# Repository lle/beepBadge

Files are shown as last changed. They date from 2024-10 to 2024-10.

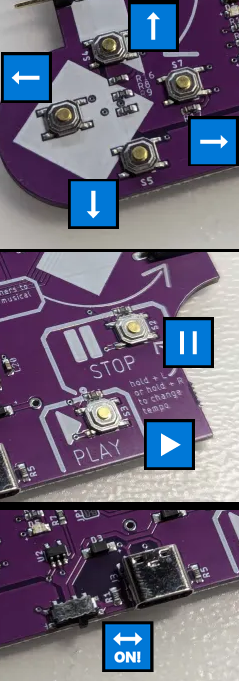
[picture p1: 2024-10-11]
img/nav.png

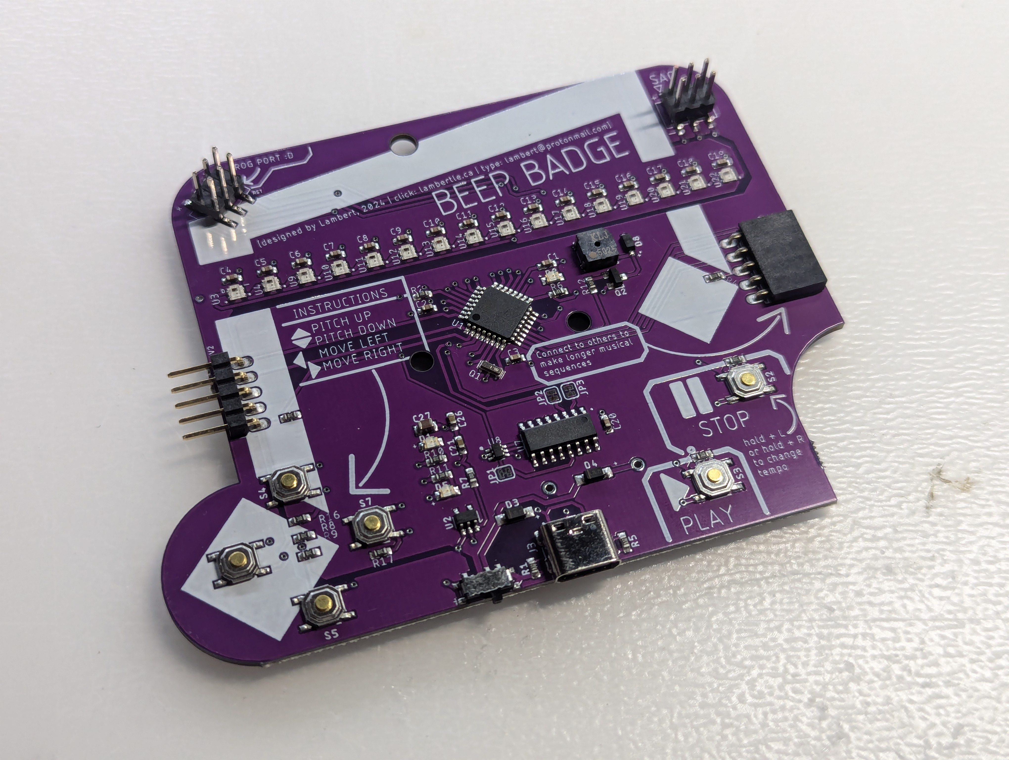
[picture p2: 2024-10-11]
img/ads.jpg

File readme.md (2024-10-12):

# BEEP BADGE
This project is inspired from a mix of concepts between an old product I was working on at my ex-job, a badge I wanted to make for a rave, the animal crossing tune creator. 
Result: a weird beeper badge XD

## Instruction
Go meet people at the con. Plug your badges together. The first person on the left presses "PLAY". The badge will start playing their 
tunes from left to right. Go make the coolest musical sequence!

## How to Program
Use an Atmel USB-ISP (USBASP) to flash the firmware. There is a programming connector at the top left of the badge labeled "Prog Port". Note the positive (+), negative (-) and reset (rst) label around the connector. Use it to match with the pinout of the USB-ISP. 
I used VScode+platformio to program and compile the firmware

## Acknowledgment
I would like to thank Angel for their help in beta-testing the badge as they are much 
more musically inclined than 
I will ever be ^.^

Parts of the design from the Northsec Pegasis badge and the "Hello my name is" badge was used to rush the design of this badge.

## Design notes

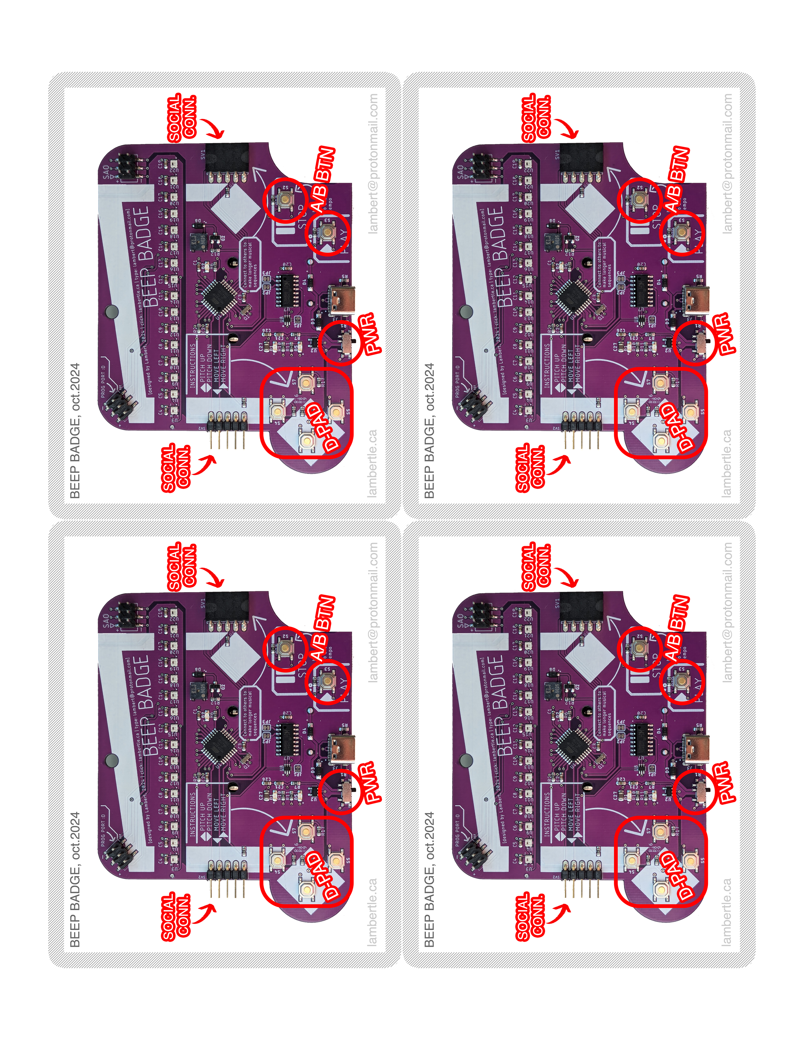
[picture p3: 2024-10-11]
img/frontpage.png

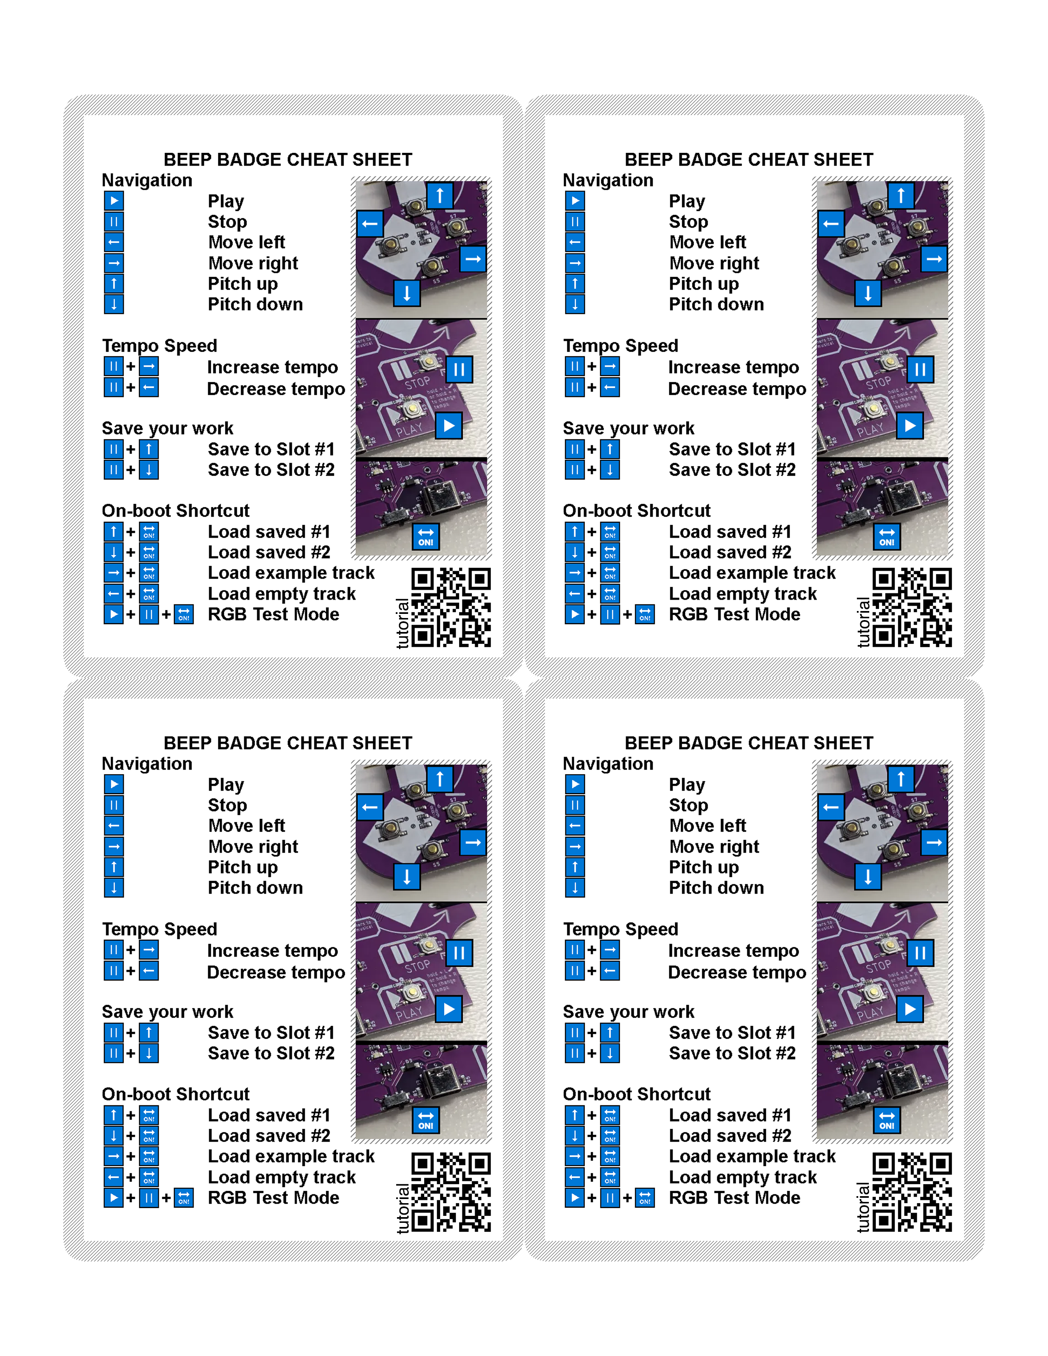
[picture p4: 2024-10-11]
img/cheatSheet.png

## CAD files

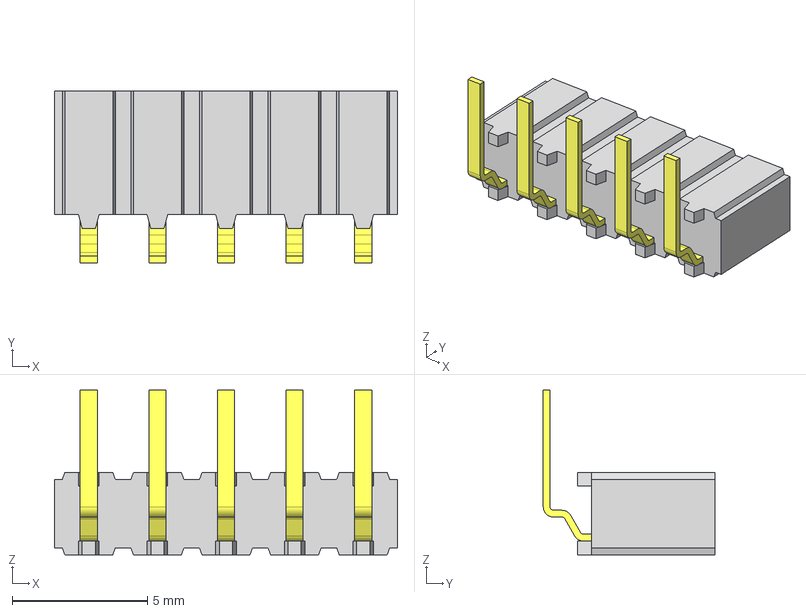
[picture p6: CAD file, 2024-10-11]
hw/cad/5pinFemale_CES-105-02-T-S-RA.stp
12.7 x 6.35 x 6.10 mm
010502SRA
CES-105-01-S_socket

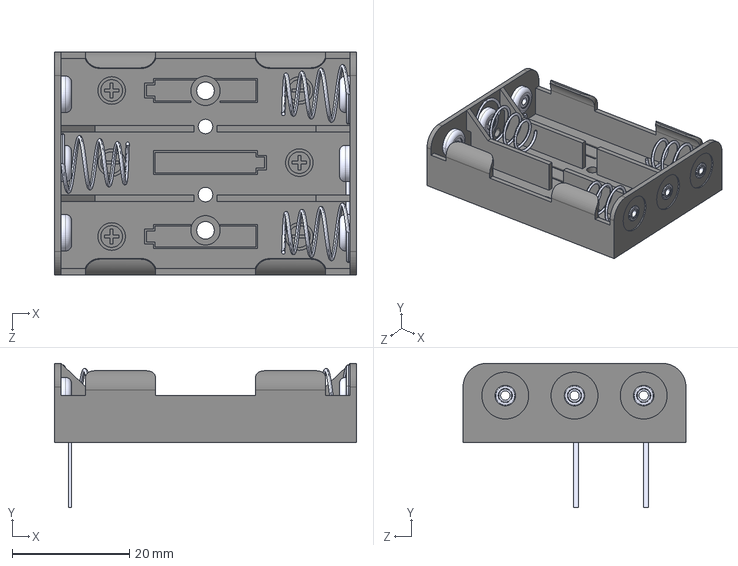
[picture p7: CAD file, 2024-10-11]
hw/cad/BC3AAAPC-battery3x-STEP-56544.STEP
51.5 x 24.6 x 38.0 mm

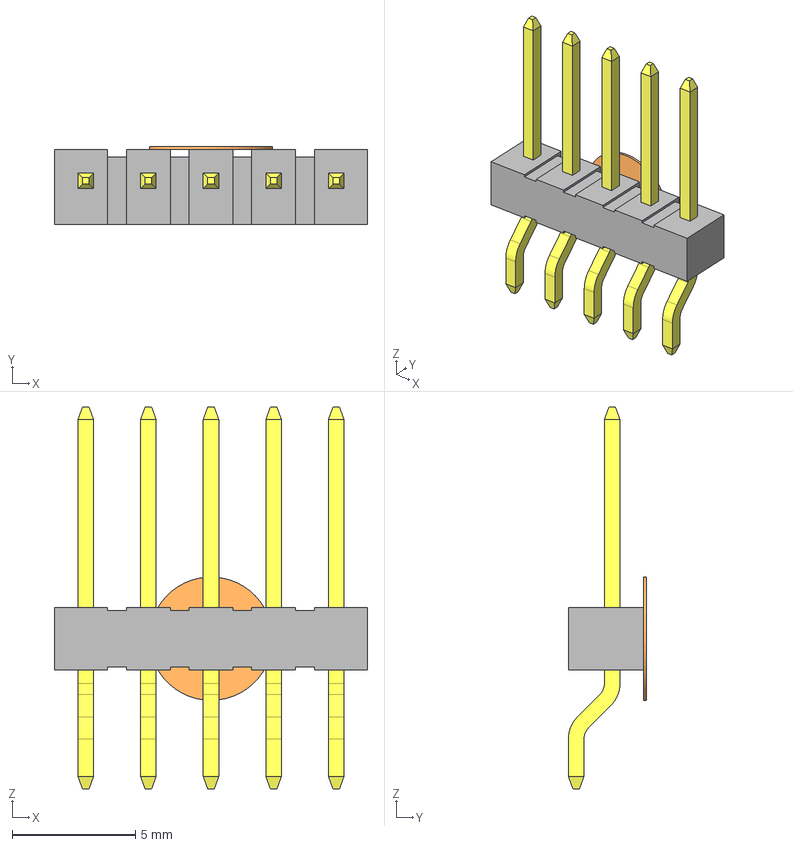
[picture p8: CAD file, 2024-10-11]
hw/cad/5pinMale_TSM-105-02-S-SH-K.stp
12.7 x 3.18 x 15.5 mm
T-1S6-15(-02-5-SH)
TSM_polyimide_film
TSM-105-02-SH_body

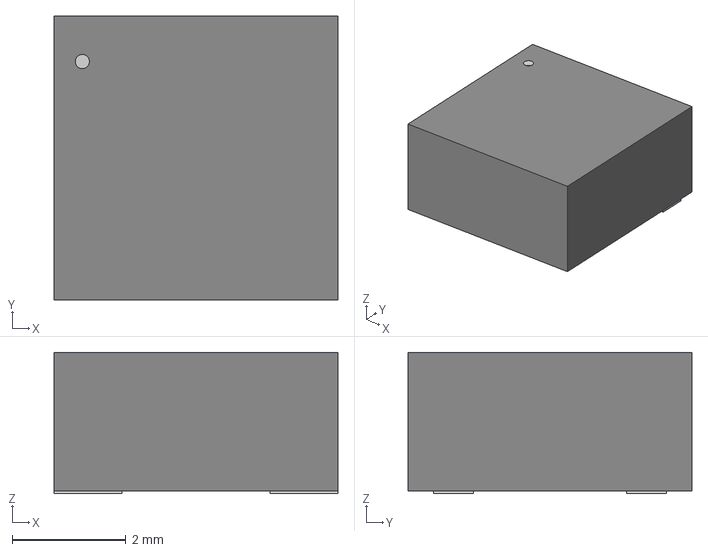
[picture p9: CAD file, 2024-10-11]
hw/cad/KLJ-5025_KKG.step
5.00 x 5.00 x 2.49 mm

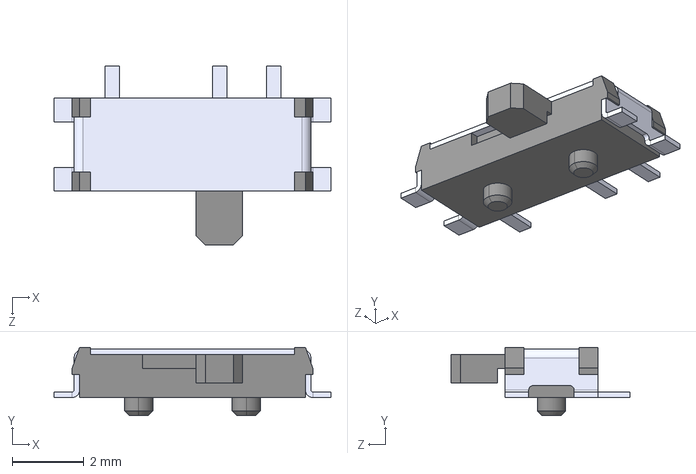
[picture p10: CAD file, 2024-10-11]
hw/cad/PCM12SMTR-powerSw-STEP-56544.STEP
7.72 x 1.91 x 4.98 mm

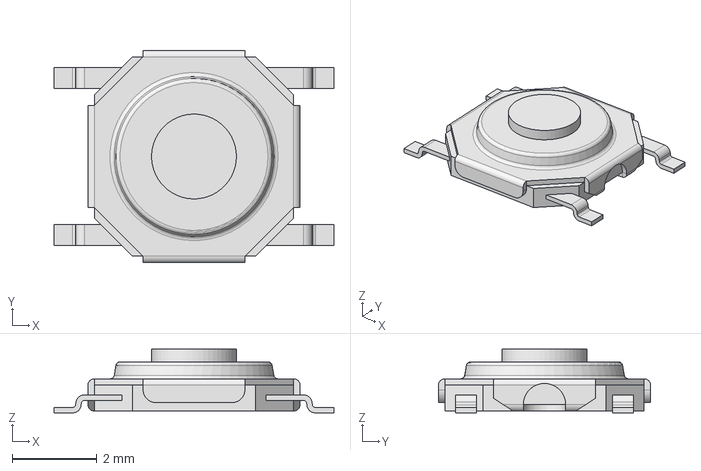
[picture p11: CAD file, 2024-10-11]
hw/cad/TL3342F160QG-tactileSw-STEP-520916.STEP
6.60 x 5.00 x 1.50 mm

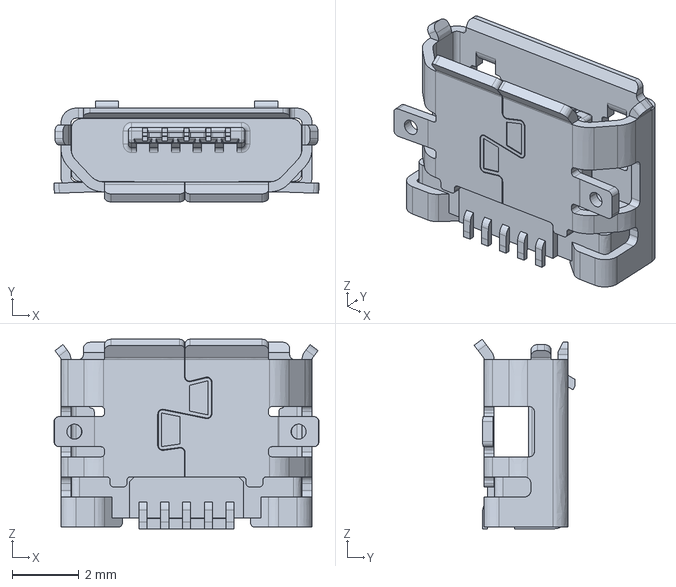
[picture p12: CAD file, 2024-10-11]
hw/cad/10118192-0001LF-microUSB-STEP-533217.STEP
7.91 x 3.01 x 5.66 mm

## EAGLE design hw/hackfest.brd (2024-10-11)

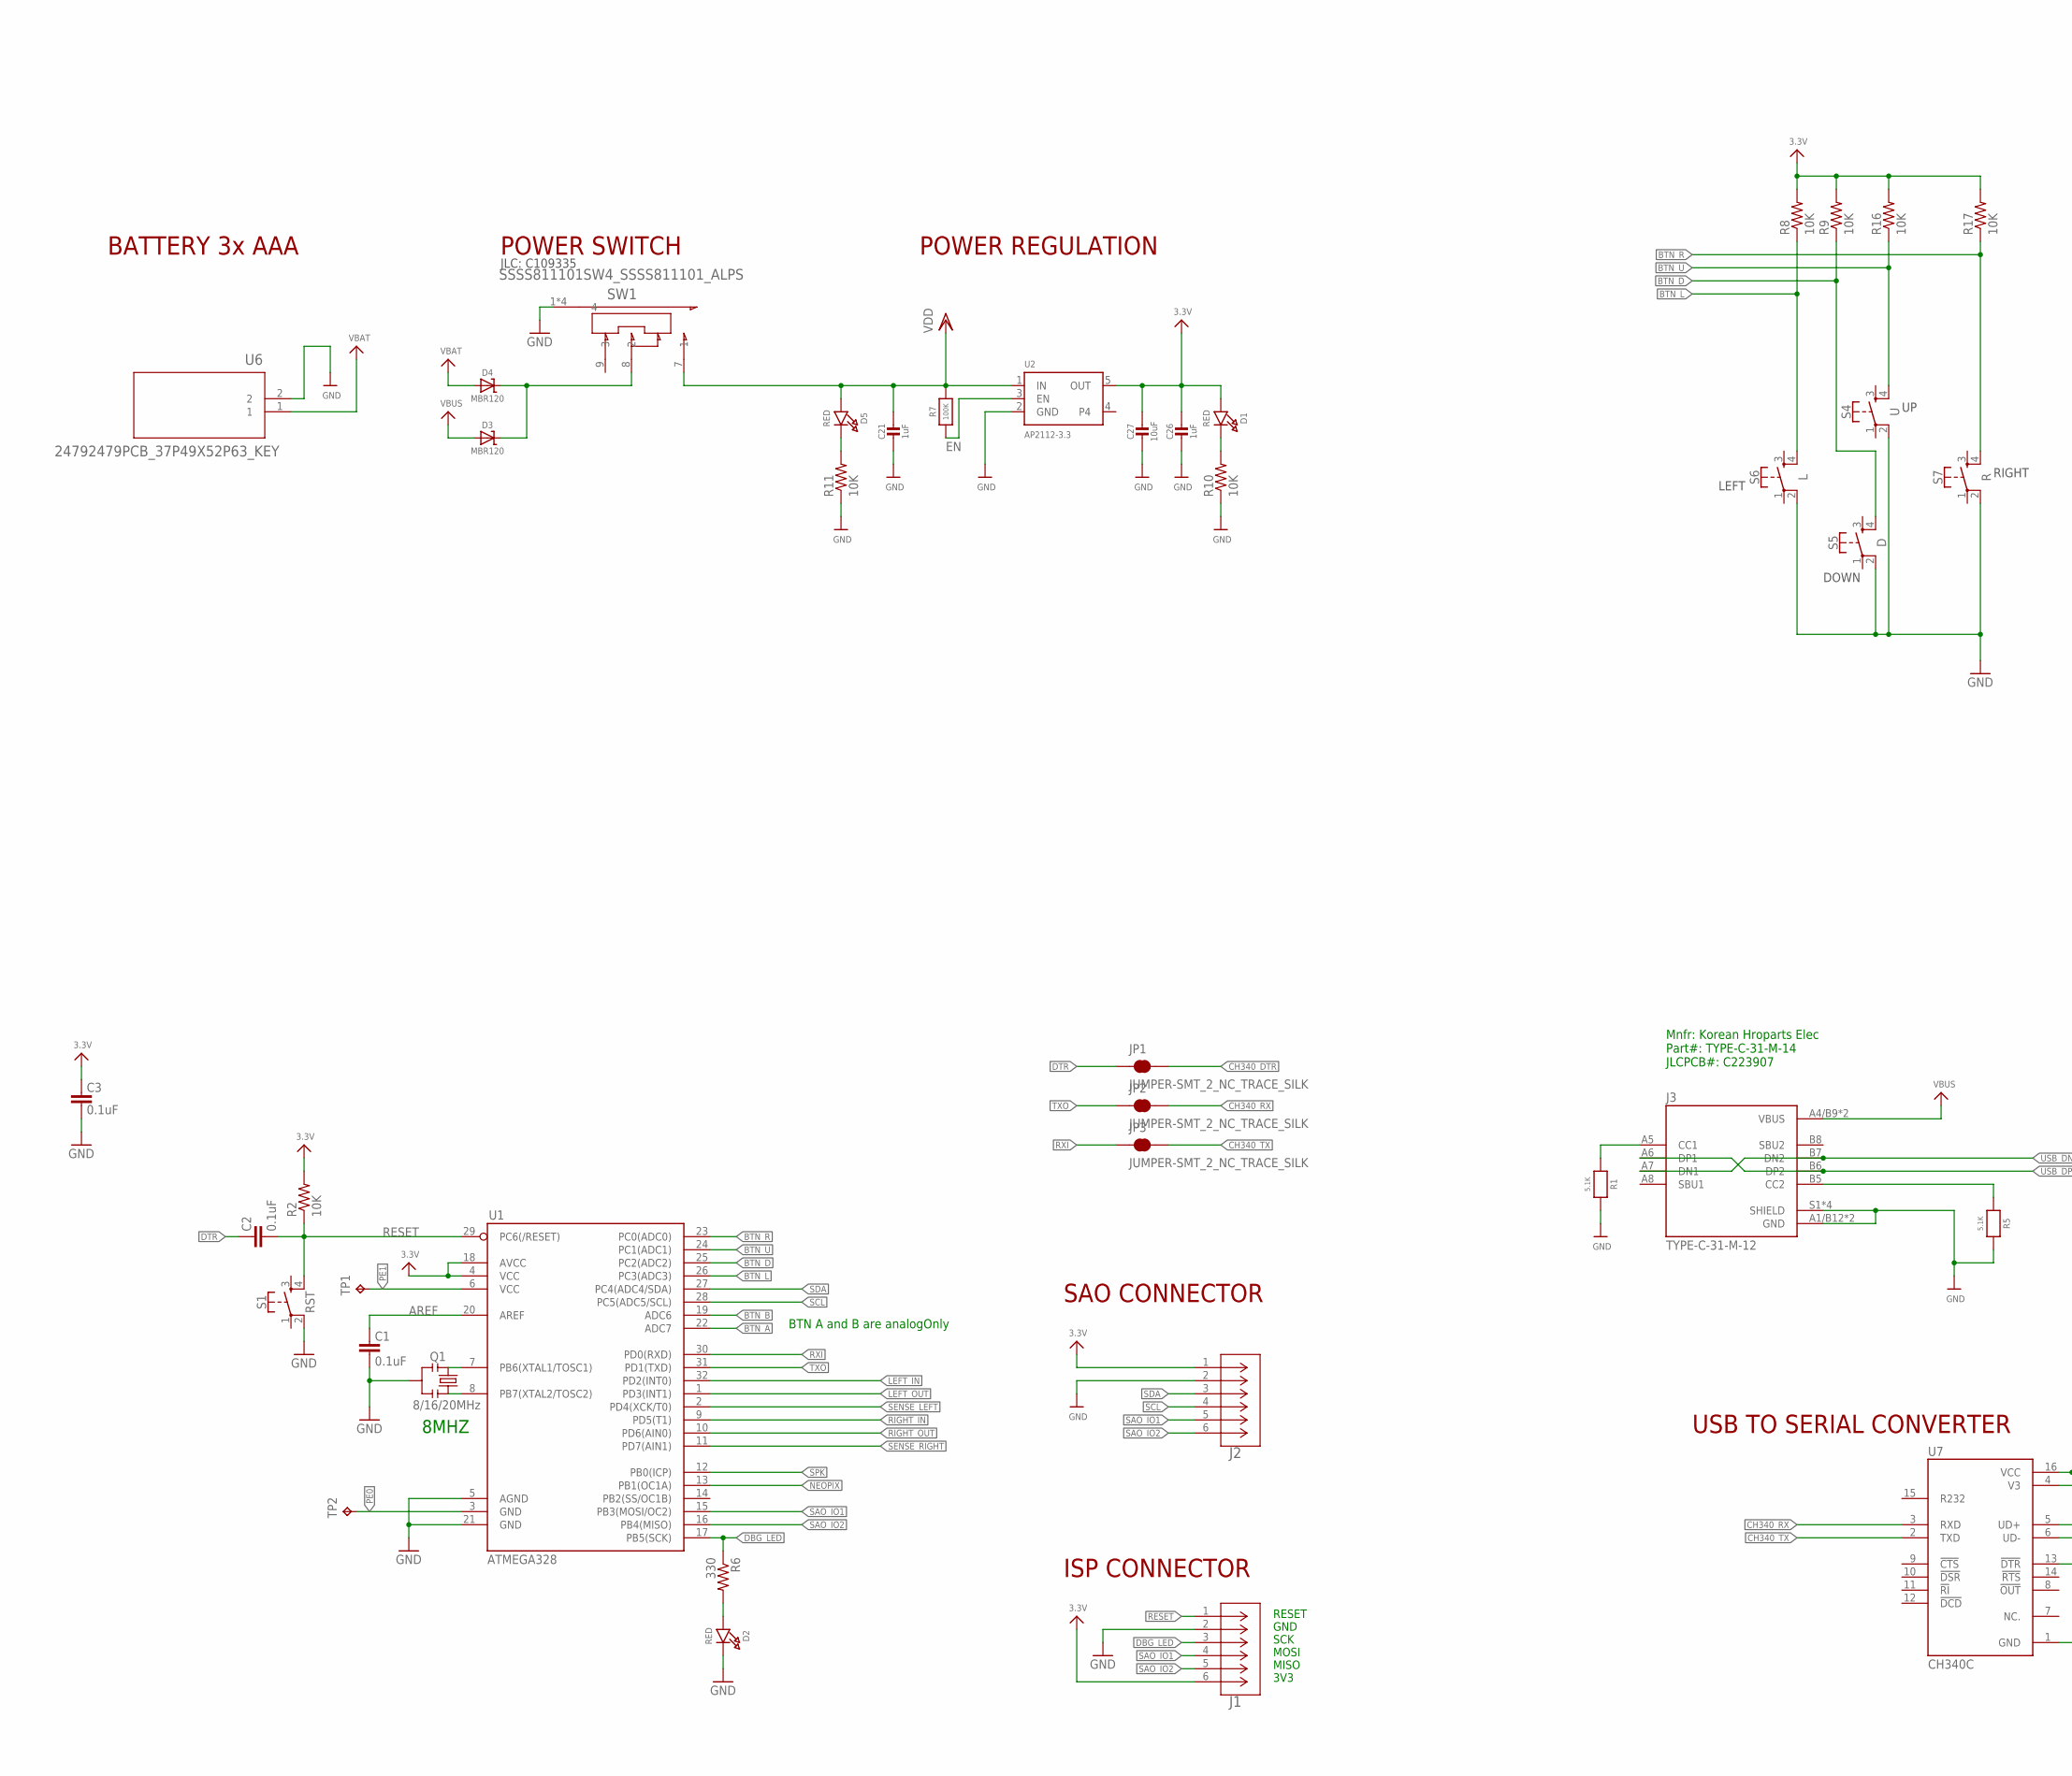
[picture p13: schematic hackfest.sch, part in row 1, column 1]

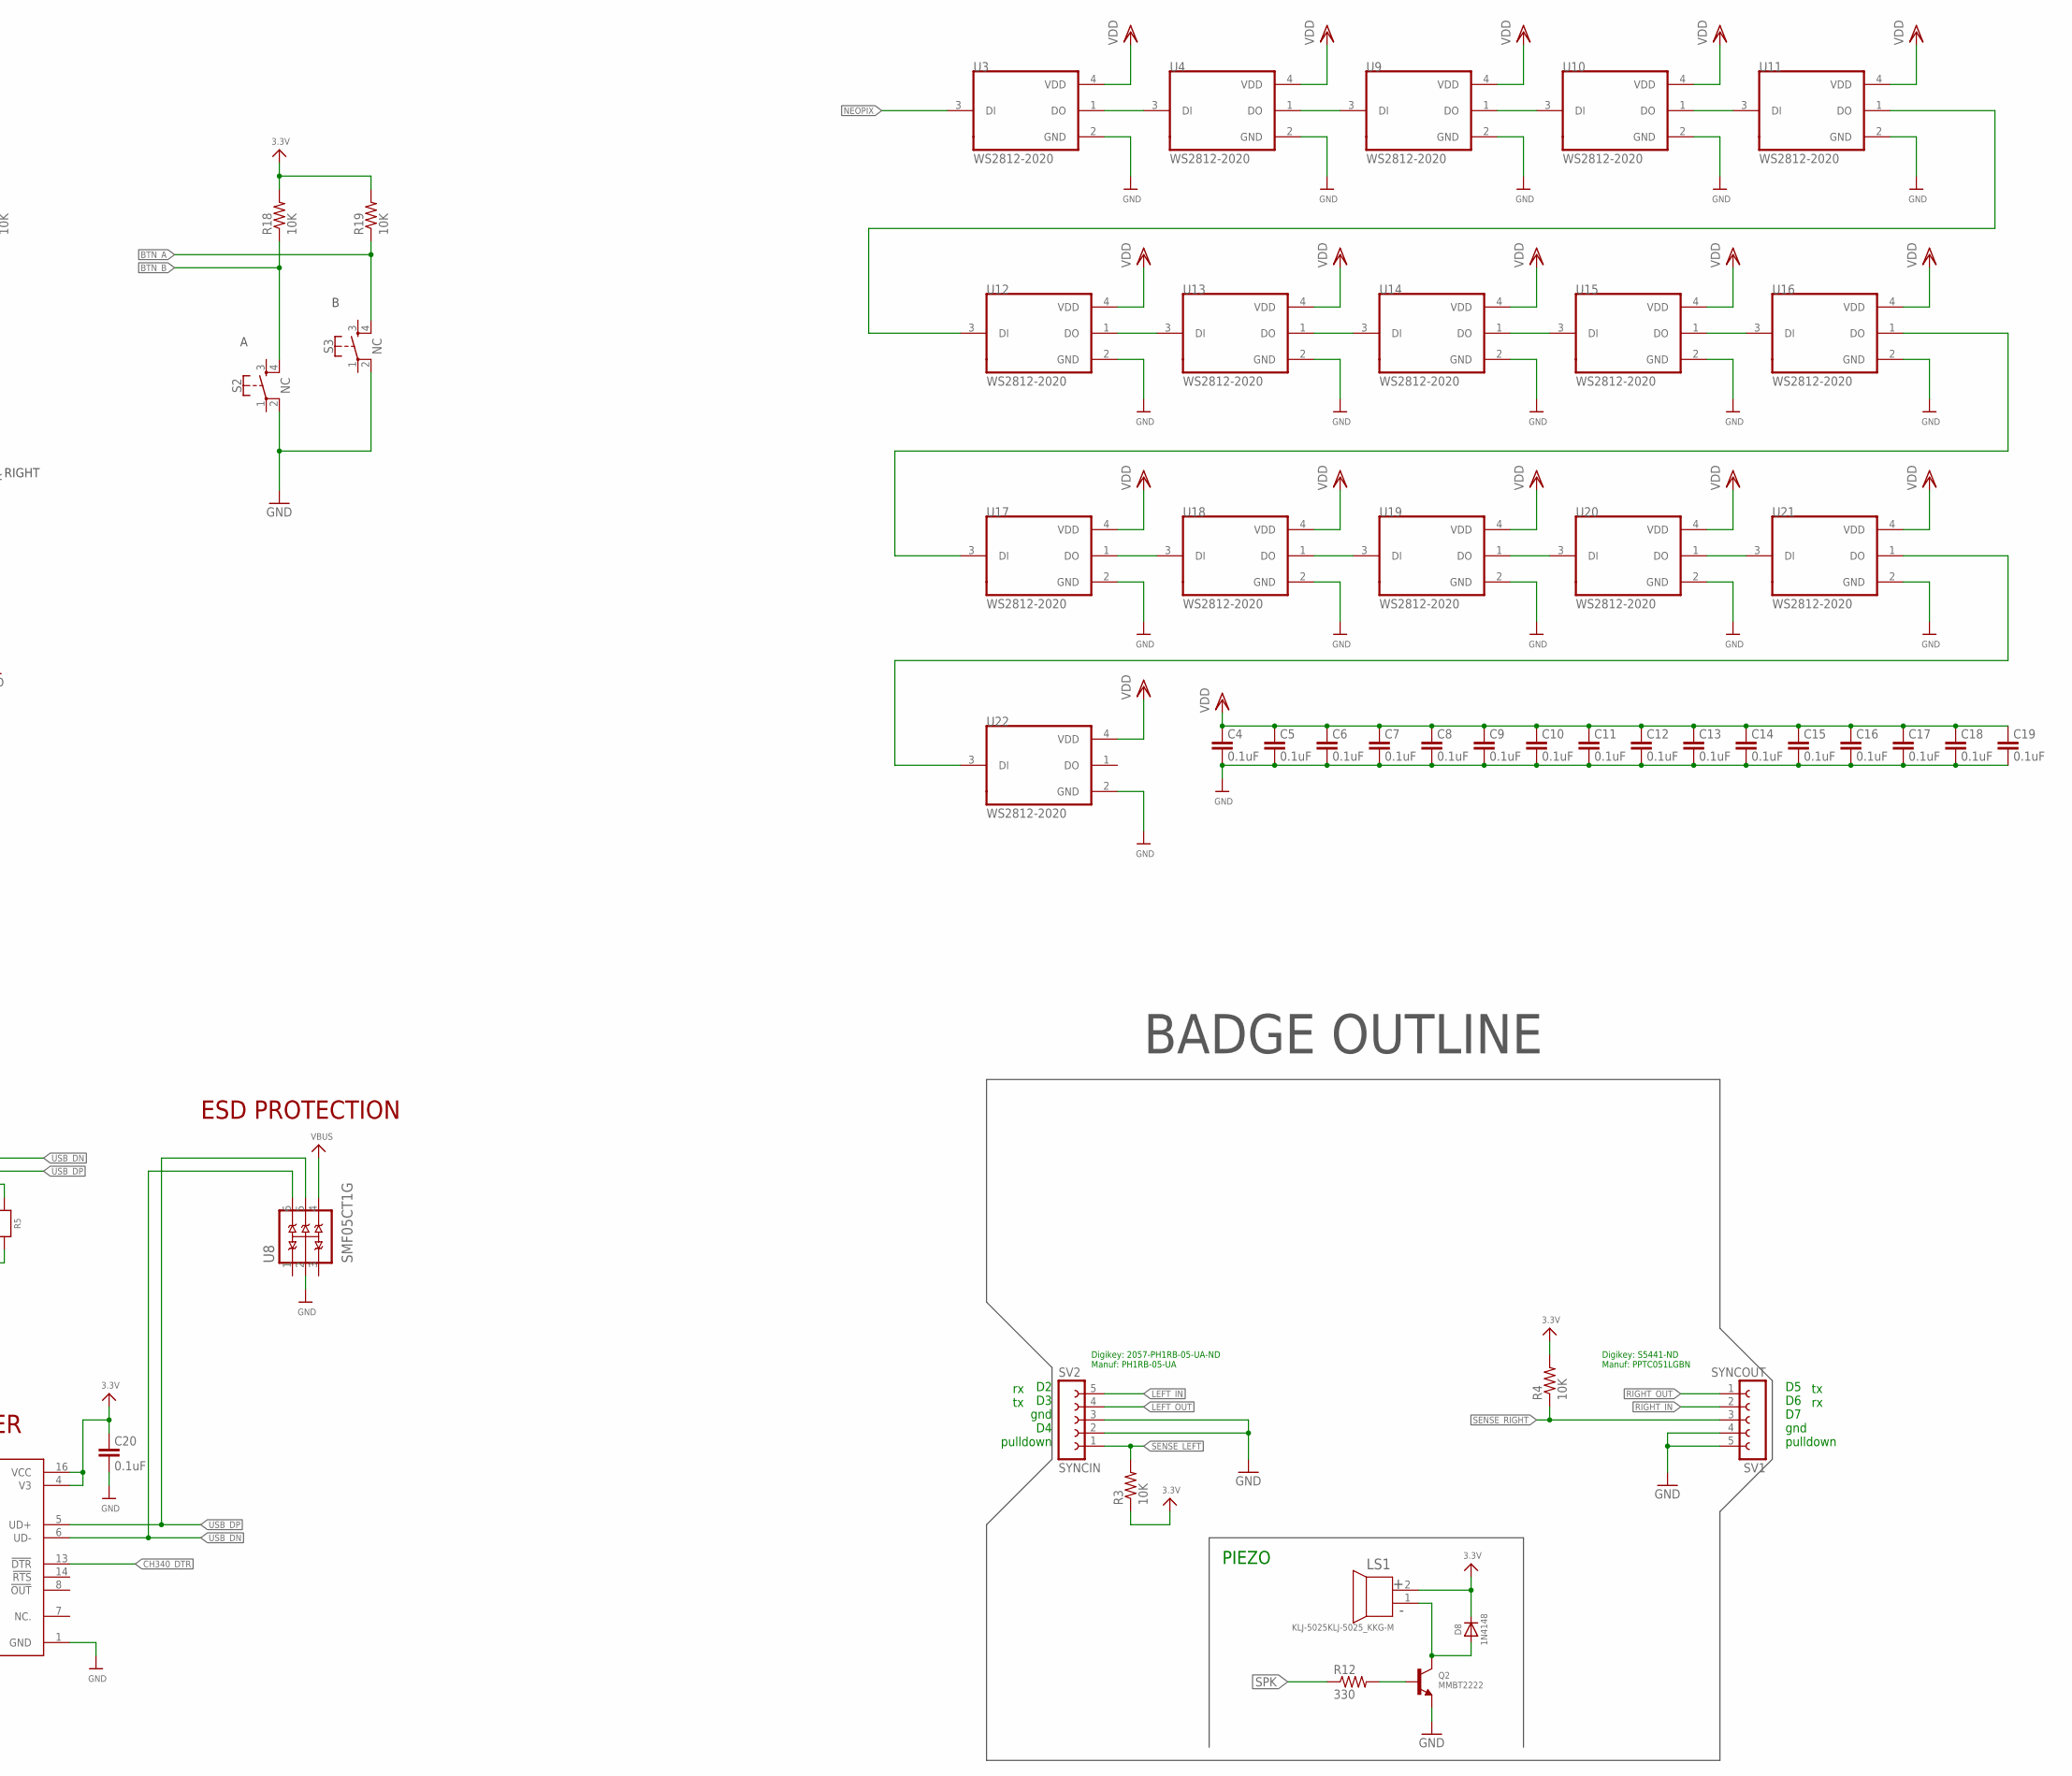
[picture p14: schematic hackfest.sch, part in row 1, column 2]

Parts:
C1, C2, C3, C4, C5, C6, C7, C8, C9, C10, C11, C12, C13, C14, C15, C16, C17, C18, C19, C20: 0.1uF; 0603-CAP
C21, C26: 1uF; 0603-NO@1
C27: 10uF; 0805-NO
D1, D2, D5: RED; CHIPLED_0805_NOOUTLINE
D3, D4: MBR120; SOD-123
D8: 1N4148; SOD-323
J1, J2: SSW-103-22-F-D-VS-K-TRCON3_SSW-D-DUMZ_HDR_SAI; CON3_SSW-D-DUMZ_HDR_SAI
J3: TYPE-C-31-M-12; HRO_TYPE-C-31-M-12
JP1, JP2, JP3: JUMPER-SMT_2_NC_TRACE_SILK; SMT-JUMPER_2_NC_TRACE_SILK
LS1: KLJ-5025KLJ-5025_KKG-M; KLJ-5025_KKG-M
Q1: 8/16/20MHz; RESONATOR-SMD-1:1
Q2: MMBT2222; SOT23-WIDE
R1, R5: 5.1K; 0603-NO
R2, R3, R4, R8, R9, R10, R11, R16, R17, R18, R19: 10K; 0603-RES
R6, R12: 330; 0603-RES
R7: 100K; 0603-NO
S1: RST; TACTILE_SWITCH_SMD_5.2MM
S2, S3: NC; TACTILE_SWITCH_SMD_5.2MM
S4: U; TACTILE_SWITCH_SMD_5.2MM
S5: D; TACTILE_SWITCH_SMD_5.2MM
S6: L; TACTILE_SWITCH_SMD_5.2MM
S7: R; TACTILE_SWITCH_SMD_5.2MM
SV1: SYNCOUT; FE05W
SV2: SYNCIN; FE05W
SW1: SSSS811101SW4_SSSS811101_ALPS; SW4_SSSS811101_ALPS
TP1, TP2: TPB1,27; B1,27
U1: ATMEGA328; TQFP32-08
U2: AP2112-3.3; SOT23-5
U3, U4, U9, U10, U11, U12, U13, U14, U15, U16, U17, U18, U19, U20, U21, U22: WS2812-2020; LED_WS2812-2020
U6: 24792479PCB_37P49X52P63_KEY; 2479PCB_37P49X52P63_KEY
U7: CH340C; SOIC127P600X180-16N
U8: SMF05CT1G; SOT65P210X110-6N

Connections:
3.3V: C3.2, C20.2, C26.1, C27.1, D1.A, D8.C, J1.6, J2.1, LS1.2, R2.2, R3.1, R4.2, R8.2, R9.2, R16.2, R17.2, R18.2, R19.2, U1.4 (VCC), U1.18 (AVCC), U2.5 (OUT), U7.4 (V3), U7.16 (VCC)
AREF: C1.2, U1.20 (AREF)
BTN_A: R19.1, S3.4, U1.22 (ADC7)
BTN_B: R18.1, S2.4, U1.19 (ADC6)
BTN_D: R9.1, S5.4, U1.25 (PC2(ADC2))
BTN_L: R8.1, S6.4, U1.26 (PC3(ADC3))
BTN_R: R17.1, S7.4, U1.23 (PC0(ADC0))
BTN_U: R16.1, S4.4, U1.24 (PC1(ADC1))
CH340_DTR: JP1.2, U7.13 (!DTR)
CH340_RX: JP2.2, U7.3 (RXD)
CH340_TX: JP3.2, U7.2 (TXD)
DBG_LED: J1.3, R6.1, U1.17 (PB5(SCK))
DTR: C2.2, JP1.1
EN: R7.1, U2.3 (EN)
GND: C1.1, C3.1, C4.1, C5.1, C6.1, C7.1, C8.1, C9.1, C10.1, C11.1, C12.1, C13.1, C14.1, C15.1, C16.1, C17.1, C18.1, C19.1, C20.1, C21.2, C26.2, C27.2, D2.C, J1.2, J2.2, J3.A1/B12 (GND), J3.B1/A12 (GND), J3.S1 (SHIELD), J3.S2 (SHIELD), J3.S3 (SHIELD), J3.S4 (SHIELD), Q1.2, Q2.2 (E), R1.2, R5.2, R10.1, R11.1, S1.2, S2.2, S3.2, S4.2, S5.2, S6.2, S7.2, SV1.4, SV1.5, SV2.2, SV2.3, SW1.1 (4), SW1.2 (4), SW1.3 (4), SW1.4, U1.5 (AGND), U1.21 (GND), U2.2 (GND), U3.2 (GND), U4.2 (GND), U6.2, U7.1 (GND), U8.2 (A), U9.2 (GND), U10.2 (GND), U11.2 (GND), U12.2 (GND), U13.2 (GND), U14.2 (GND), U15.2 (GND), U16.2 (GND), U17.2 (GND), U18.2 (GND), U19.2 (GND), U20.2 (GND), U21.2 (GND), U22.2 (GND)
LEFT_IN: SV2.5, U1.32 (PD2(INT0))
LEFT_OUT: SV2.4, U1.1 (PD3(INT1))
unnamed: Q1.3, U1.8 (PB7(XTAL2/TOSC2))
unnamed: Q1.1, U1.7 (PB6(XTAL1/TOSC1))
unnamed: U4.1 (DO), U9.3 (DI)
unnamed: U9.1 (DO), U10.3 (DI)
unnamed: U3.1 (DO), U4.3 (DI)
unnamed: U10.1 (DO), U11.3 (DI)
unnamed: D2.A, R6.2
unnamed: U11.1 (DO), U12.3 (DI)
unnamed: U12.1 (DO), U13.3 (DI)
unnamed: U13.1 (DO), U14.3 (DI)
unnamed: U14.1 (DO), U15.3 (DI)
unnamed: U15.1 (DO), U16.3 (DI)
unnamed: U16.1 (DO), U17.3 (DI)
unnamed: U17.1 (DO), U18.3 (DI)
unnamed: U18.1 (DO), U19.3 (DI)
unnamed: U19.1 (DO), U20.3 (DI)
unnamed: U20.1 (DO), U21.3 (DI)
unnamed: U21.1 (DO), U22.3 (DI)
unnamed: D8.A, LS1.1, Q2.3 (C)
unnamed: Q2.1 (B), R12.2
unnamed: J3.B5 (CC2), R5.1
unnamed: J3.A5 (CC1), R1.1
unnamed: D3.C, D4.C, SW1.8 (2)
unnamed: D5.C, R11.2
unnamed: D1.C, R10.2
NEOPIX: U1.13 (PB1(OC1A)), U3.3 (DI)
PE0: TP2.TP, U1.3 (GND)
PE1: TP1.TP, U1.6 (VCC)
RESET: C2.1, J1.1, R2.1, S1.4, U1.29 (PC6(/RESET))
RIGHT_IN: SV1.2, U1.9 (PD5(T1))
RIGHT_OUT: SV1.1, U1.10 (PD6(AIN0))
RXI: JP3.1, U1.30 (PD0(RXD))
SAO_IO1: J1.4, J2.5, U1.15 (PB3(MOSI/OC2))
SAO_IO2: J1.5, J2.6, U1.16 (PB4(MISO))
SCL: J2.4, U1.28 (PC5(ADC5/SCL))
SDA: J2.3, U1.27 (PC4(ADC4/SDA))
SENSE_LEFT: R3.2, SV2.1, U1.2 (PD4(XCK/T0))
SENSE_RIGHT: R4.1, SV1.3, U1.11 (PD7(AIN1))
SPK: R12.1, U1.12 (PB0(ICP))
TXO: JP2.1, U1.31 (PD1(TXD))
USB_DN: J3.A7 (DN1), J3.B7 (DN2), U7.6 (UD-), U8.6 (C5)
USB_DP: J3.A6 (DP1), J3.B6 (DP2), U7.5 (UD+), U8.5 (C4)
VBAT: D4.A, U6.1
VBUS: D3.A, J3.A4/B9 (VBUS), J3.B4/A9 (VBUS), U8.4 (C3)
VDD: C4.2, C5.2, C6.2, C7.2, C8.2, C9.2, C10.2, C11.2, C12.2, C13.2, C14.2, C15.2, C16.2, C17.2, C18.2, C19.2, C21.1, D5.A, R7.2, SW1.7 (1), U2.1 (IN), U3.4 (VDD), U4.4 (VDD), U9.4 (VDD), U10.4 (VDD), U11.4 (VDD), U12.4 (VDD), U13.4 (VDD), U14.4 (VDD), U15.4 (VDD), U16.4 (VDD), U17.4 (VDD), U18.4 (VDD), U19.4 (VDD), U20.4 (VDD), U21.4 (VDD), U22.4 (VDD)

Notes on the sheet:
POWER REGULATION
BATTERY 3x AAA
DOWN
LEFT
RIGHT
USB TO SERIAL CONVERTER
ESD PROTECTION
BADGE OUTLINE
Mnfr: Korean Hroparts Elec Part#: TYPE-C-31-M-14 JLCPCB#: C223907
SAO CONNECTOR
RESET GND SCK MOSI MISO 3V3
ISP CONNECTOR
Digikey: S5441-ND Manuf: PPTC051LGBN
Digikey: 2057-PH1RB-05-UA-ND Manuf: PH1RB-05-UA
8MHZ
D2 D3 gnd D4 pulldown
D5 D6 D7 gnd pulldown
rx tx
tx rx
BTN A and B are analogOnly
PIEZO
JLC: C109335
POWER SWITCH

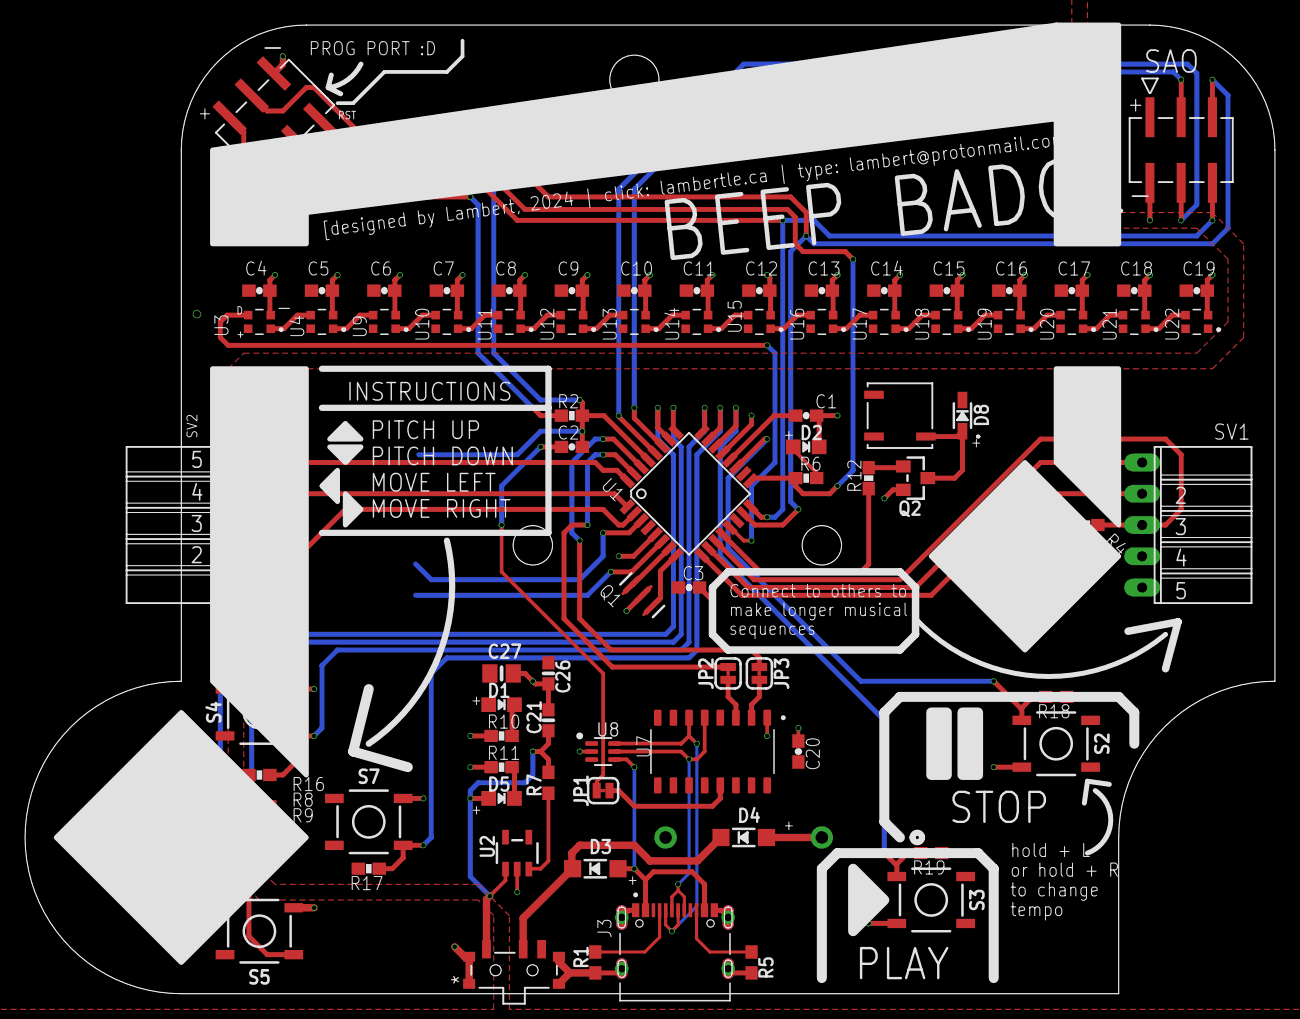
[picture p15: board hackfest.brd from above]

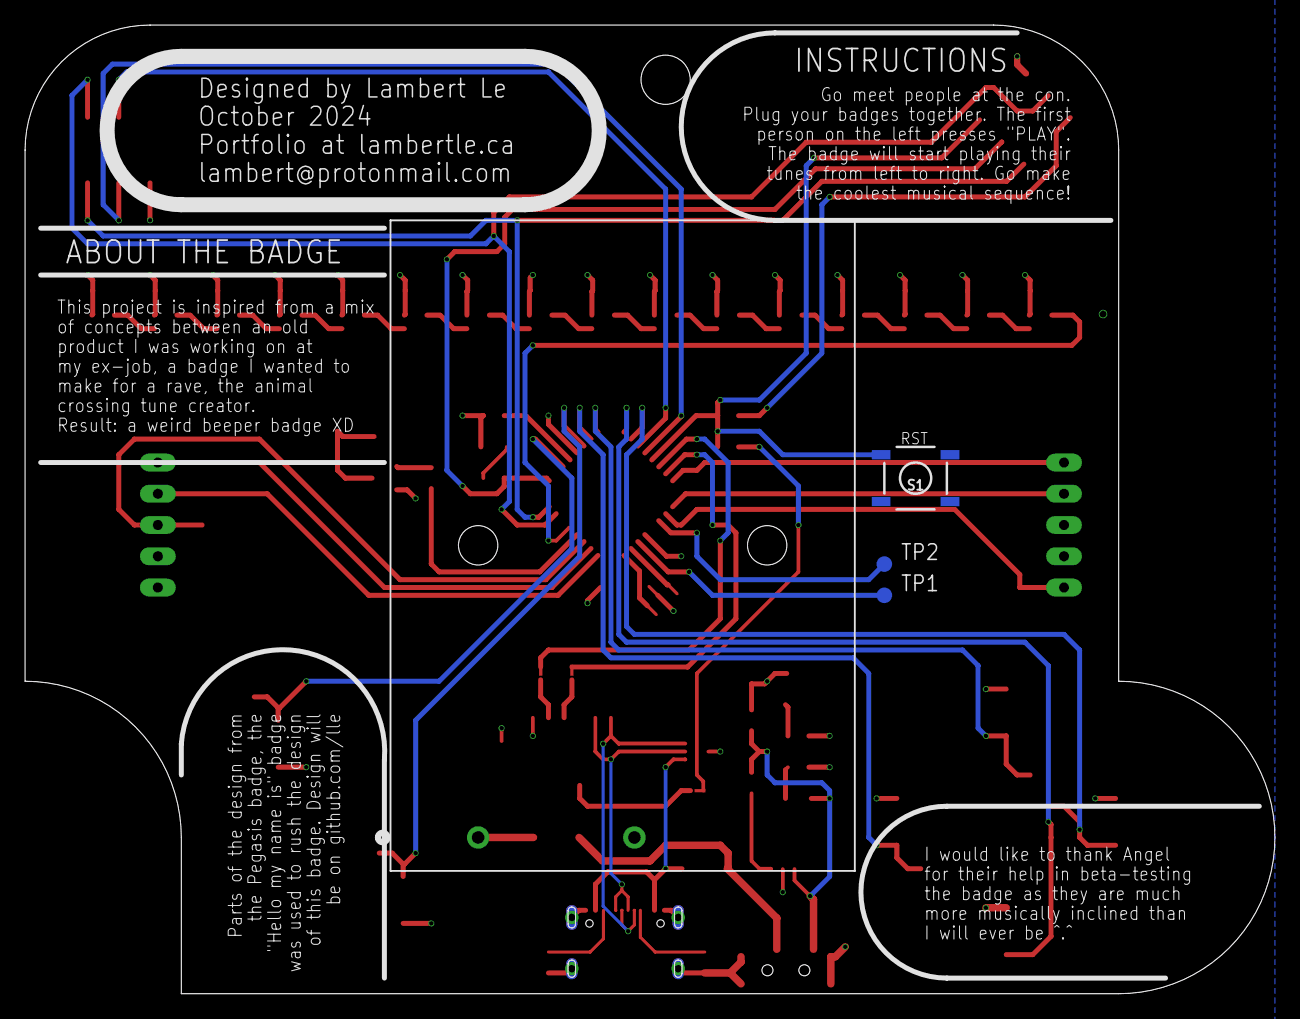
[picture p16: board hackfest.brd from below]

Board: 2 copper layers, 101.6 x 78.7 mm, 87 parts (4 on the bottom side), 62 nets.

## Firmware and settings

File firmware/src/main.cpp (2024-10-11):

#include "../inc/definitions.h"
#include "../inc/testModule.h"
#include "../inc/rgbControl.h"
#include "../inc/buttonControl.h"
#include "../inc/sequencerControl.h"
#include "../inc/soundControl.h"
#include "../inc/commControl.h"
#define F_CPU 8000000L    //<---------- hardware requirement, assume Vcc worse case 2.7V, 8Mhz ext.crystal recommended (see datasheet Figure 29-1)

// ****************************************************
// --------- INITIALIZATION --------- 
// ****************************************************
void setup()
{
  button_init();
  comPort_init();
  soundControl_init();
  rgbLed_init();

  pinMode(DEBUG_LED, OUTPUT);
  digitalWrite(DEBUG_LED, HIGH);
  Serial.begin(115200);
  Serial.println("\n\n---------\n\rBEEP BADGE\n\rby Lambert\n\rOct.2024\n\r---------");
  sequencer_bootChkBtn(); //load different preset depending on which d-pad button is pressed

  if(analogRead(BTN_A) == 0 && analogRead(BTN_B) == 0) //if A and B are held down during boot, enter neopixel test mode
    rgbLed_testLoopLocking();

  rgbLed_render();
  sequencer_print();
  digitalWrite(DEBUG_LED, LOW);
}


// ****************************************************
// --------- MAIN LOOP --------- 
// ****************************************************
uint32_t ts_blink = 0;
uint32_t ts_btnScan = 0;
#define BTN_SCAN_DEFAULT 135
#define BTN_SCAN_FAST 90
uint16_t BTN_SCAN_DELAY = BTN_SCAN_DEFAULT;
void loop() 
{
  comPort_checkLeftPlaySignal();

  if(millis() - ts_btnScan > BTN_SCAN_DELAY)
  {
    ts_btnScan = millis();
    button_listener();

    if(button_isAnyHold() == true) //if the user is holding the button, accelerate btn_scan
      BTN_SCAN_DELAY = BTN_SCAN_FAST;
    else
      BTN_SCAN_DELAY = BTN_SCAN_DEFAULT;
  }

  rgbLed_autoReactivateBlinker();
  if(millis() - ts_blink > CURSOR_BLK_DELAY && rgbLed_getIsBlinkerEnabled() == 1) //
  {
    ts_blink = millis();
    rgbLed_cursorBlinkRun();
  }
}

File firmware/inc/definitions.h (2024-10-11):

#ifndef DEFINITIONS

#include "Arduino.h"
#include <Adafruit_NeoPixel.h>

// -------------- GPIO CONFIG --------------
#define BTN_U A1
#define BTN_L A3
#define BTN_R A0
#define BTN_D A2
#define BTN_A A7
#define BTN_B A6
#define DEBUG_LED 13
#define LEFT_IN 2
#define LEFT_OUT 3
#define LEFT_SENSE 4
#define RIGHT_IN 5
#define RIGHT_OUT 6
#define RIGHT_SENSE 7

// -------------- NEOPIXEL COLORS --------------
#define NEOPIX_PIN 9
#define NUMPIX 16

// -------------- NOTES TONES --------------
#define BUZZER_PIN 8    // change this to whichever pin you want to use
#define MIN_TONE 0
#define MAX_TONE 16

// Timestamps Schedulers
#define CURSOR_BLK_DELAY 50

#endif

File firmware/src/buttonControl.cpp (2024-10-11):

#include "../inc/definitions.h"
#include "../inc/rgbControl.h"
#include "../inc/sequencerControl.h"
#include "../inc/soundControl.h"
#include "../inc/buttonControl.h"
#include "../inc/memoryControl.h"

#define HELD_DELAY 500

void button_init()
{
  pinMode(BTN_U, INPUT_PULLUP);
  pinMode(BTN_L, INPUT_PULLUP);
  pinMode(BTN_R, INPUT_PULLUP);
  pinMode(BTN_D, INPUT_PULLUP);
  pinMode(BTN_A, INPUT);
  pinMode(BTN_B, INPUT);
}

bool button_isAnyPressed()
{
  bool isPressed = false;
  if(analogRead(BTN_A) == 0 || analogRead(BTN_B) == 0 )
    isPressed = true;
  else if(digitalRead(BTN_U) == LOW || digitalRead(BTN_D) == LOW || digitalRead(BTN_L) == LOW || digitalRead(BTN_R) == LOW)
    isPressed = true;
  
  return isPressed;
}

bool button_isAnyHold()
{
  static uint32_t ts_lastBtnPressed = 0;
  static bool pressDetected = false;
  if(button_isAnyPressed() == true && pressDetected == false) //if a button was not pressed during the last scan AND is pressed now
  {
    ts_lastBtnPressed = millis(); //record time of btn press detected
    pressDetected = true;         //assert the flag
    return false;                 //return false for now, wait for next cycle to confirm if a button is held
  }
  else if(  button_isAnyPressed() == true 
            && pressDetected == true 
            && millis()-ts_lastBtnPressed>HELD_DELAY  ) //if the button is still being held after the 2nd cycle, then return true
  {
    return true;
  }
  else if( button_isAnyPressed() == false && pressDetected == true) //if the user stop holding the button, return false
  {
    pressDetected = false;
    return false;
  }
  return false;
}

void button_listener()
{
  //  ------ PLAYBACK and TEMPO CONTROL ------
  if( analogRead(BTN_A) == 0 ) 
  {
    sequencer_play();
  }
  else if( analogRead(BTN_B) == 0 && digitalRead(BTN_R) == LOW) //increase tempo
  {
    rgbLed_blinkMask_disable();
    tempo_increase();
  }
  else if( analogRead(BTN_B) == 0 && digitalRead(BTN_L) == LOW) //decrease tempo
  {
    rgbLed_blinkMask_disable();
    tempo_decrease();
  }
  else if( analogRead(BTN_B) == 0 && digitalRead(BTN_U) == LOW) //save animation slot1
  {
    memory_saveSlot1();
    rgbLed_saveAnimation();
    rgbLed_render();
  }
  else if( analogRead(BTN_B) == 0 && digitalRead(BTN_D) == LOW) //save animation slot2
  {
    memory_saveSlot2();
    rgbLed_saveAnimation();
    rgbLed_render();
  }
  else if( analogRead(BTN_B) == 0) //decrease tempo
  {
    rgbLed_tempoBar_activate();
    rgbLed_renderTempo(soundControl_getTempo());
  }


  // ------ INCREASE OR DECREASE PITCH ------
  else if( digitalRead(BTN_U) == LOW && analogRead(BTN_B) != 0) 
  { 
    uint8_t curr_index = sequencer_getCursorIndex();
    if(sequencer_getValue(curr_index) < MAX_TONE)
    {
      rgbLed_blinkMask_disable();
      sequencer_setValue(curr_index, sequencer_getValue(curr_index) + 1);
      sound_playPreview(sequencer_getValue(curr_index));
      rgbLed_render();
    }
    sequencer_print();
  }

  else if( digitalRead(BTN_D) == LOW && analogRead(BTN_B) != 0) 
  {  
    uint8_t curr_index = sequencer_getCursorIndex();
    if(sequencer_getValue(curr_index) > MIN_TONE)
    {
      rgbLed_blinkMask_disable();
      sequencer_setValue(curr_index, sequencer_getValue(curr_index) - 1);
      sound_playPreview(sequencer_getValue(curr_index));
      rgbLed_render();
    }
    sequencer_print();
  }


  // ------ MOVE LEFT OR RIGHT ------
  else if( digitalRead(BTN_L) == LOW ) 
  { 
    rgbLed_blinkMask_enable();
    if(sequencer_getCursorIndex() > 0) 
    {
      sequencer_cursorIndexDecrement();
      sound_lowBuzz();
      rgbLed_render();
    }
    else
    {
      sound_errorBuzz();
    }
    sequencer_print();
  }

  else if( digitalRead(BTN_R) == LOW ) 
  {  
    rgbLed_blinkMask_enable();
    if(sequencer_getCursorIndex() < 15) 
    {
      sequencer_cursorIndexIncrement();
      sound_lowBuzz();
      rgbLed_render();
    }
    else
    {
      sound_errorBuzz();
    }
    sequencer_print();
  }
}

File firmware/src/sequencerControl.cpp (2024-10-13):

#include "../inc/definitions.h"
#include "../inc/rgbControl.h"
#include "../inc/sequencerControl.h"
#include "../inc/soundControl.h"
#include "../inc/commControl.h"
#include "../inc/memoryControl.h"

#define 	_A	  1	  //	220   (technically A3)
#define 	_As	  2	  //	233
#define 	_B	  3	  //	247   (underscore before '_x' = 1 octave down)
#define 	C	    4 	//	262
#define 	Cs	  5	  //	277
#define 	D	    6	  //	294
#define 	Ds	  7	  //	311
#define 	E	    8	  //	330
#define 	F4	  9	  //	349  (calling this F4, because F is already used by Arduino)
#define 	Fs	  10	//	370
#define 	G	    11	//	392
#define 	Gs	  12	//	415
#define 	A	    13	//	440
#define 	As	  14	//	466
#define 	B	    15	//	494
#define 	C_	  16	//	523   (technically C5)  (underscore after 'x_' = next octave up)

const uint8_t SEQ_LGT = 16;
uint8_t sequencer[SEQ_LGT] =  {A,G,A,F4,     C,F4,_A,0,   A,G,A,F4,    C,F4,_A,0};  //16 timeslots available for sound sequencing
uint8_t sequencePreset[][SEQ_LGT] =  {  /*each number correspond to the tone requested for playback (see _TONES)*/                                         
                                          {A,G,A,F4,    C,F4,_A,0,    A,G,A,F4,      C,F4,_A,0    },  //popcorn part1
                                          {D,E,F4,E,    F4,D,E,D,     E,C,D,C,       _A,C,D,0     },  //popcorn part2
                                          {A,B,C_,B,    C_,A,B,A,     B,G,A,G,      A,_A,A,0      },  //popcorn part3
                                          {1,1,1,1,     1,1,1,1,      1,1,1,1,      1,1,1,1,      }  //twinkle twinkly little star
                                      };
uint32_t sequencerRGB[SEQ_LGT];
uint8_t cursorIndex = 0;

//PROTOTYPE
void sequencer_printIdWithLetter(uint8_t id);


// ------ GET/SET FUNCTIONS ------
uint8_t sequencer_getCursorIndex()
{
  return cursorIndex;
}

void sequencer_cursorIndexIncrement()
{
  cursorIndex++;
}

void sequencer_cursorIndexDecrement()
{
  cursorIndex--;
}

uint8_t sequencer_getValue(uint8_t index)
{
  return sequencer[index];
}

void sequencer_setValue(uint8_t index, uint8_t value)
{
  sequencer[index] = value;
}


// ------ FUNCTIONS -------
void sequencer_bootChkBtn()
{
  //scan for single-press on boot
  int8_t presetSelected = -1;  

  //Loading USER sequences from memory
  if(digitalRead(BTN_U) == LOW)
  {
    Serial.println("Load memory slot #1");
    if(memory_loadSlot1() == 0)
      presetSelected = 0;  //loading memory failed, load preset #0 instead
    else
      presetSelected = -1;  //loading successful, ignore preset
  }
  else if(digitalRead(BTN_D) == LOW)
  {
    Serial.println("Load memory slot #2");
    if(memory_loadSlot2() == 0)
      presetSelected = 1;  //loading memory failed, load preset #0 instead
    else
      presetSelected = -1;  //loading successful, ignore preset
  }

  //Loading PRE-PROGRAMMED sequences
  else if(digitalRead(BTN_R) == LOW)
    presetSelected = 2;
  else if(digitalRead(BTN_L) == LOW)
    presetSelected = 3;

  //Play animation
  if(presetSelected == -1)
  {
    rgbLed_loadAnimation();
    Serial.println("Sequence");
  }
  else
  {
    rgbLed_loadAnimation();
    Serial.print("preset selected=");
    Serial.println(presetSelected);
    for(int i=0; i<SEQ_LGT; i++)
    {
      sequencer[i] = sequencePreset[presetSelected][i];
    }
  }
}

void sequencer_print()
{
  for(int i=0; i<SEQ_LGT; i++)
  {
    sequencer_printIdWithLetter(sequencer[i]);
    
    if(i == cursorIndex)
      Serial.print("<");
    Serial.print("\t");
  }
  Serial.println();
}

void sequencer_play()
{
  Serial.println("PLAYING");

  for (int i=0; i<SEQ_LGT; i++)   // Remember, the array is twice the number of notes (notes + durations)
  {
    if(analogRead(BTN_B) == 0) //FORCE EXIT is B is being held
    {
      sound_errorBuzz();
      rgbLed_render();
      Serial.println("Force Exit");
      return;
    }

    rgbLed_highlight(i);
    Serial.print("^");
    soundControl_playsound(sequencer[i]);
    Serial.print("\t");
  }

  if(comPort_isRightBadgeDetected() == true)  //if right badge detected, than send play signal to it 
  {
    comPort_setRightOutput();
    delay(80); //hold signal to ensure the next badge reads it
  }
  rgbLed_render(); //re-render without the rgbLed_highlight
  noTone(BUZZER_PIN);  // stop the waveform generation before the next note.
  Serial.println();
  sequencer_print(); //reprint sequencer to serial
  comPort_unsetRightOutput(); //de-assert playback gpio for the right badge 
}

void sequencer_printIdWithLetter(uint8_t id)
{
  switch (id) 
  {
    case 0:
      Serial.print("-");
      break;
    case 1:
      Serial.print("A3");
      break;
    case 2:
      Serial.print("A3s");
      break;
    case 3:
      Serial.print("B3");
      break;
    case 4:
      Serial.print("C4");
      break;
    case 5:
      Serial.print("C4s");
      break;
    case 6:
      Serial.print("D4");
      break;
    case 7:
      Serial.print("D4s");
      break;
    case 8:
      Serial.print("E4");
      break;
    case 9:
      Serial.print("F4");
      break;
    case 10:
      Serial.print("F4s");
      break;
    case 11:
      Serial.print("G4");
      break;
    case 12:
      Serial.print("G4s");
      break;
    case 13:
      Serial.print("A4");
      break;
    case 14:
      Serial.print("A4s");
      break;
    case 15:
      Serial.print("B4");
      break;
    case 16:
      Serial.print("C5_");
      break;
  }
}

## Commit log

2024-10-11 Release for Hackfest
    Firmware and hardware are now open source for all to play with
    [10118192-0001LF-microUSB-STEP-533217.STEP, 5pinFemale_CES-105-02-T-S-RA.stp, 5pinMale_TSM-105-02-S-SH-K.stp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]
2024-10-13 corrected reported bug in the uart output
    [sequencerControl.cpp]

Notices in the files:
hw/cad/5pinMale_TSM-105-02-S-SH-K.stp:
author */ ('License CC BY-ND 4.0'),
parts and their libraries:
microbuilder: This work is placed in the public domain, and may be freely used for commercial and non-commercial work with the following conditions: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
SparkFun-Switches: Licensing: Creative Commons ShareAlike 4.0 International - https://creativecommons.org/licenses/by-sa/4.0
